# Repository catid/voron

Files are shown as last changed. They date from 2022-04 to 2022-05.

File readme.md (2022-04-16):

## Voron Files

These are some files related to Voron 2.4 printers that I've built.  Some frequently asked questions on Voron discord are answered in `faq.md`, some mods I've designed are provided and documented, and outdated copies of my personal printer configuration are provided without explanation.

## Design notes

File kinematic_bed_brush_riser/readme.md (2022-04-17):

## Voron V2 Kinematic Bed Brush Riser

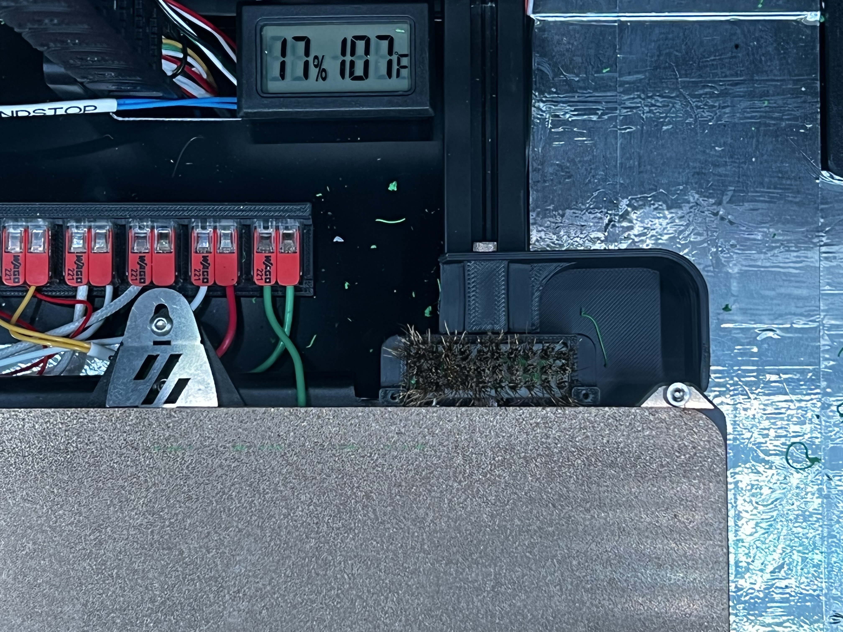
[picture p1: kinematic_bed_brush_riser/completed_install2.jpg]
Completed Install


Designed to be used with the Whoppingpochard kinematic bed mod:
https://github.com/tanaes/whopping_Voron_mods/tree/main/kinematic_bed

This may be useful for other extra-tall beds.

## Prints:

One of either of these based on your height preference:

+ `BrushRiser16mmBolts.stl` : For 2 m3x16 mm bolts.
+ `BrushRiser20mmBolts.stl` : For 2 m3x20 mm bolts.

## Assembly:

Just install it under the Purge Bucket Brush.

I had to cut off the left Purge Bucket to fit on my printer, but the right one still works fine.

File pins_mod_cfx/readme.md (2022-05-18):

## Carbon Fiber X Axis for Pins Mod

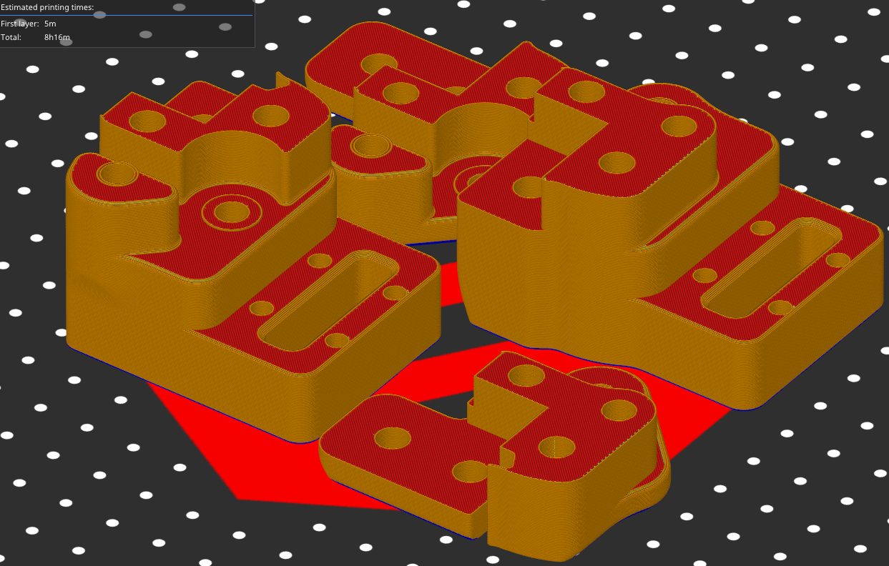
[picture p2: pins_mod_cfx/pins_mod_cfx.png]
Print


Designed to be used with the hartk pins mod:
https://github.com/hartk1213/MISC/tree/main/Voron%20Mods/Voron%202/2.4/Voron2.4_Pins_Mod/

## Prints:

+ `MGN12_xy_joint_left_lower_pinned_24r2_cfx.stl`
+ `MGN12_xy_joint_left_upper_pinned_24r2_cfx.stl`
+ `MGN12_xy_joint_right_lower_pinned_24r2_cfx.stl`
+ `MGN12_xy_joint_right_upper_pinned_24r2_cfx.stl`

## Assembly:

Just print and use in place of the original parts.

To screw in the m3 bolts for the rail, I used some pliars to hold the m3 nuts and screwed in with my other hand.

To keep the m5 nuts in place, I used some hot-glue and did one side at a time.

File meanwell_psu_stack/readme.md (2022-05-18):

## MEAN WELL 48V PSU Stack

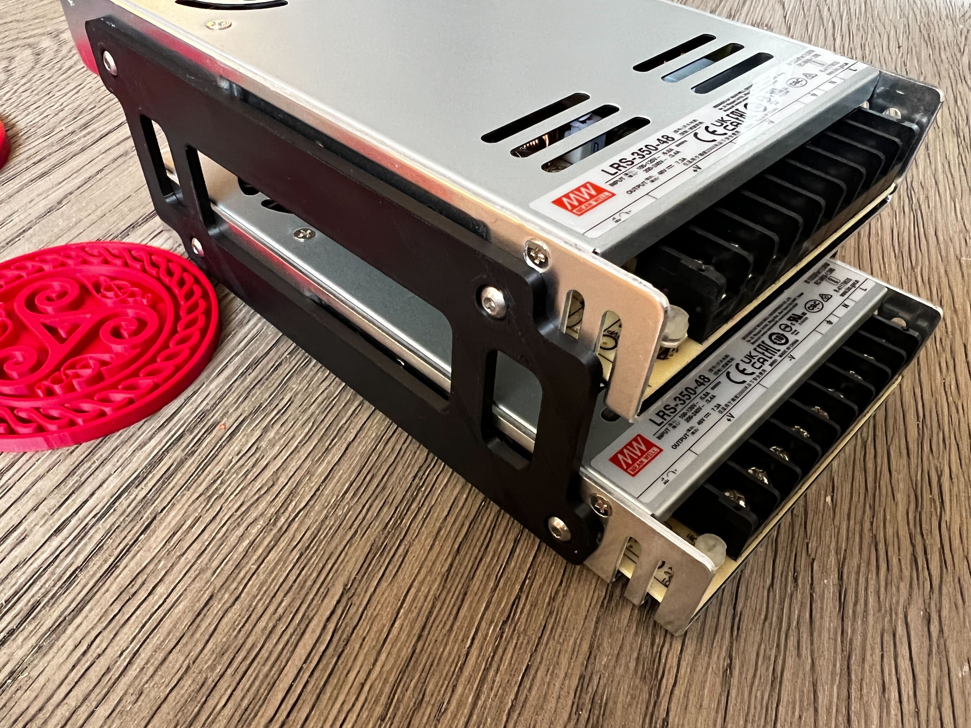
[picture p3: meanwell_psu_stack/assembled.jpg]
Assembled Stack


Because the stack is too tall for the bottom panel, I'm planning to leave off the bottom panel.

This is intended to be used for stacking a second 48V PSU on top of the first PSU in a Voron 3D printer.
My 250mm Voron is not large enough to mount a second 48V PSU in the electronics bay, and I was not able to find PSUs that were smaller and also provided enough power.

There is a 20mm offset between the two PSUs for airflow.  Both PSUs should have active cooling.  The MEAN WELL 200W PSUs do not have active cooling but the 350W versions do, and they ship fast and are fairly cheap and have good build quality.

Added an extra 20mm to the Voron feet so that the second PSU does not hit the ground, and so that it can breathe:

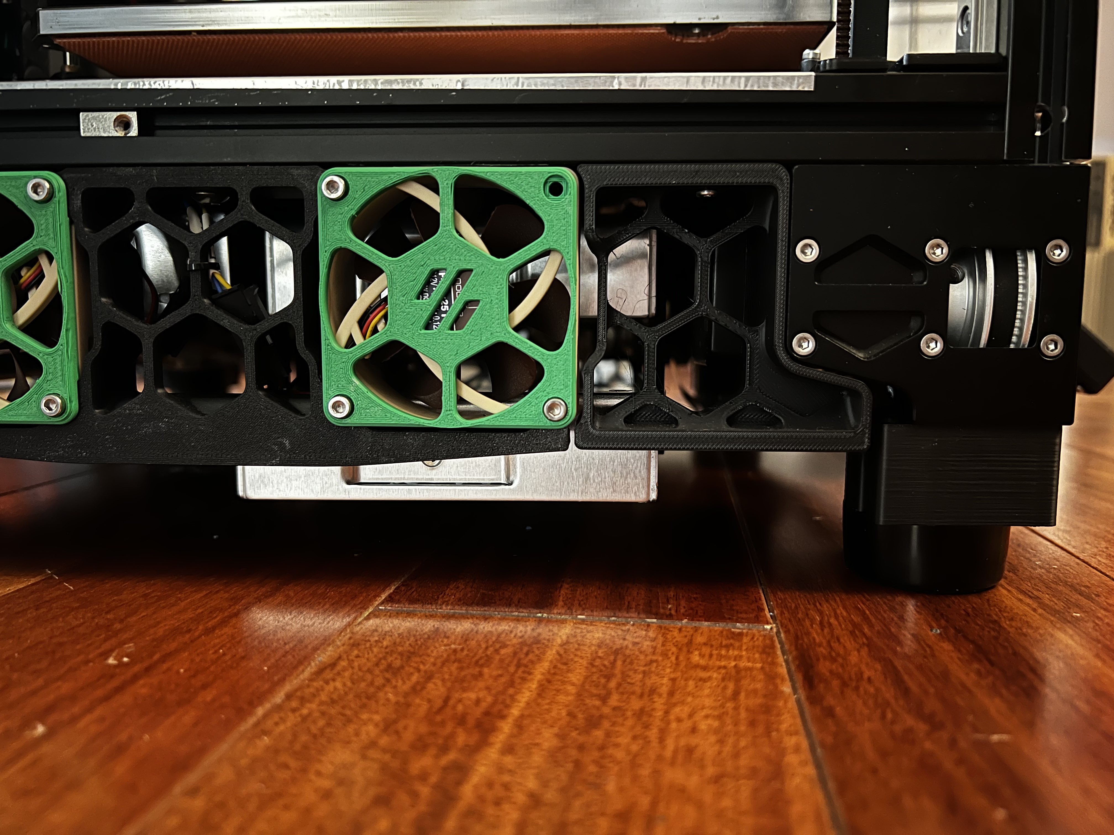
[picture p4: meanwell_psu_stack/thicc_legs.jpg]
Thicc Legs


## Materials:

Electronics:

+ 1x Actively Cooled MEAN WELL 24V PSU.  350W version works.
+ 1x Actively Cooled MEAN WELL 48V PSU.  350W version works.

Fasteners:

+ 8x m4x6 bolts

## Prints:

+ 1x `MeanwellStackLeft.stl`
+ 1x `MeanwellStackRight.stl`
+ 2x `FootSpacerAx2.stl`
+ 2x `FootSpacerBx2.stl`

They should fit on a 250mm build plate.

## Assembly:

Install using the m4x6 bolts so that the terminals are exposed as in the picture above.  Then install as normal using the typical Voron mounting option.

The bottom panel should be left off with this mod, since the stack is too tall.

The normal Voron feet spacers should be replaced by the thicc ones, which add an extra 20mm of height under the printer so that the 48V PSU can breathe and so that it doesn't hit the floor.

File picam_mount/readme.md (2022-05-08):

## Voron V2 Pi Camera Mount

Example video produced by this design: https://www.youtube.com/watch?v=63CIvoFfxug

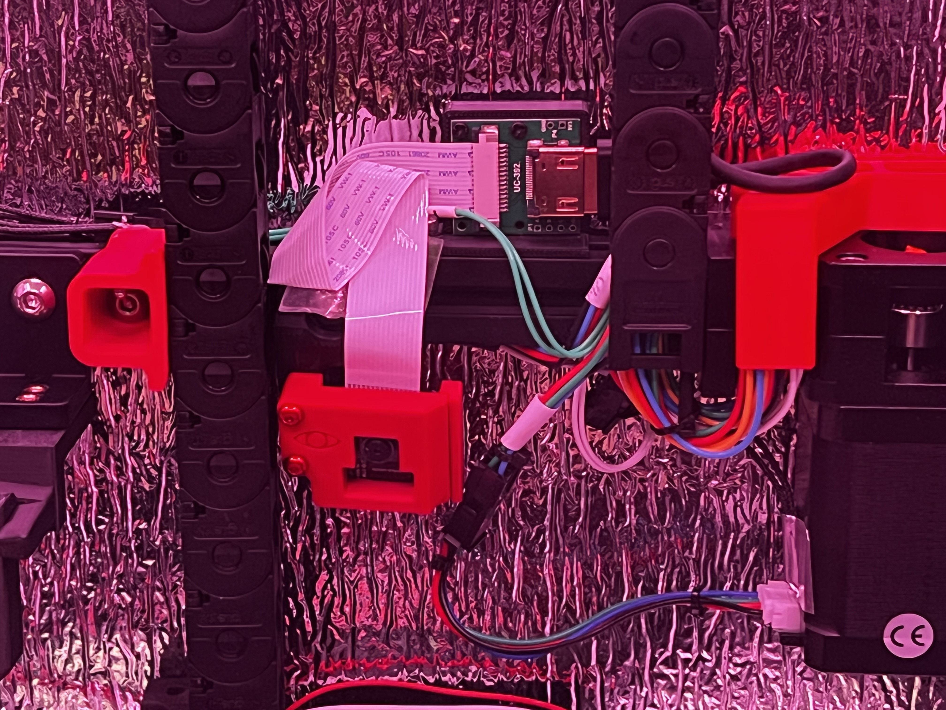
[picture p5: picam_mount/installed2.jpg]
Completed Install


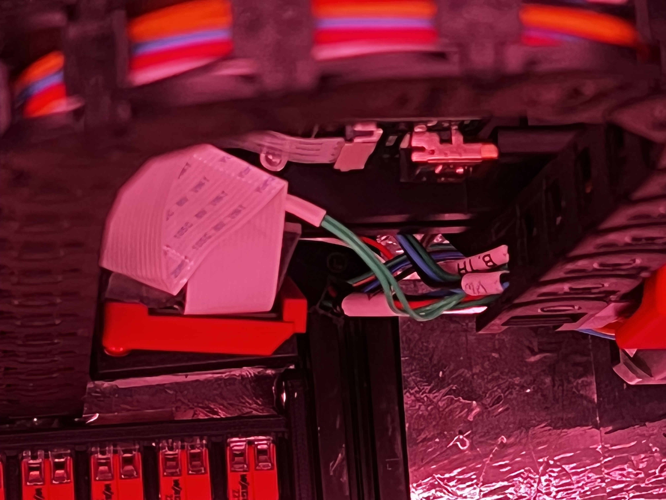
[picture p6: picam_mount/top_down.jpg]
Top Down


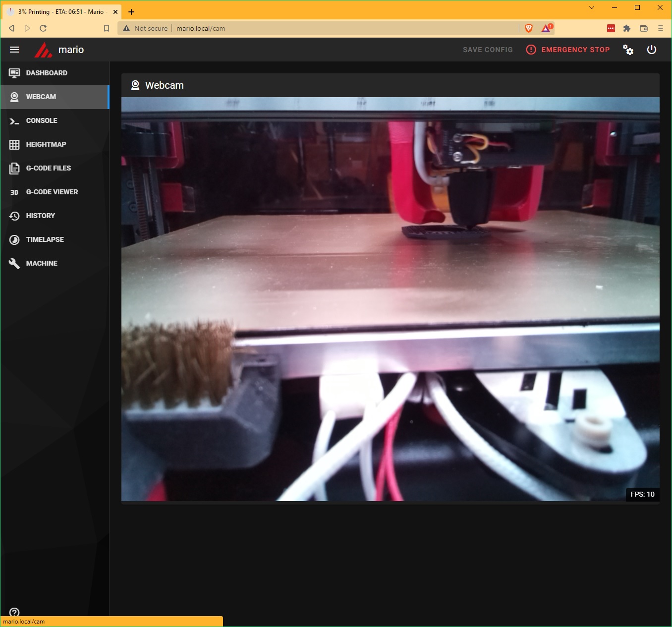
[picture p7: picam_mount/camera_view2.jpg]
Camera View


## Materials:

Electronics:

+ Official Raspberry Pi Camera Module V2 8-megapixel sensor 3280 × 2464 1080p V2.1 for Raspberry Pi 3 2 1 model B B+
+ Arducam CSI to HDMI Cable Extension Module with 15pin 60mm FPC Cable for Raspberry Pi Camera Specific (Pack of 2, 1 Set)
+ 3 foot (1 meter) HDMI cable.
+ You might need a slightly longer PiCam MIPI cable to reach from the adapter to the camera.

Fasteners:

+ Small screws that come with the HDMI adapters and PiCam - Do not throw these away!  If you lost some you can use 2-3 screws instead of 4 and share between the mounts.
+ 2x m3 Heatset insert
+ 2x m3x12 bolts (for camera)
+ 2x m3x8 bolts (for HDMI adapters)
+ 2x m3 2020 T-nut insert (for HDMI adapters)
+ 1x m5 2020 T-nut insert (for camera)
+ 1x m5x10 bolt (for camera mount)
+ Some double-sided tape to secure the MIPI cable

## Prints:

One of each of the STLs included:

+ `2020Mount.stl` : Attaches to gantry on the side under the Z cable chain.
+ `PCBHolder.stl` : Bolts to the 2020Mount and carries the Pi camera.  Small screws that come with the Pi can secure it down.
+ `CaseTop.stl` : Bolts to the PCBHolder and provides some protection for the camera.
+ `PiCamHdmiAdaptMountBay.stl` : Attaches to the side of any open 2020 extrusion near the Pi.  Terminates HDMI cable, provides PiCam CSI ribbon cable.
+ `PiCamHdmiAdaptMountGantry.stl` : Attaches to gantry on the top behind the Z cable chain, flush against the AB motor housing.  Terminates PiCam CSI ribbon cable, provides HDMI cable.

## Assembly:

Install heatset inserts into the two holes in the 2020Mount.

Install the two HDMI adapters into their mounts with their tiny bolts.

Bolt one to the top of gantry (with T-nut), and route the HDMI cable through the Z cable chain.  Bolt the other one into the electronics bay (with T-nut) close enough to the Raspberry Pi so that a CSI ribbon cable will reach to the (center) CSI port on the Pi.
Note that the one for the gantry will send the HDMI cable to the right, while the one for the electronics bay sends HDMI the wrong way for use on the gantry.

Bolt 2020Mount onto side of gantry (with T-nut) between Z cable chain.

Attach Pi camera to the HDMI adapter via ribbon cable.

Bolt PCBHolder to 2020Mount first, and then install the Pi camera with tiny bolts.
Bolt CaseTop to PCBHolder.

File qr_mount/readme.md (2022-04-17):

## Voron V2 Bondtech QR Extruder Mount

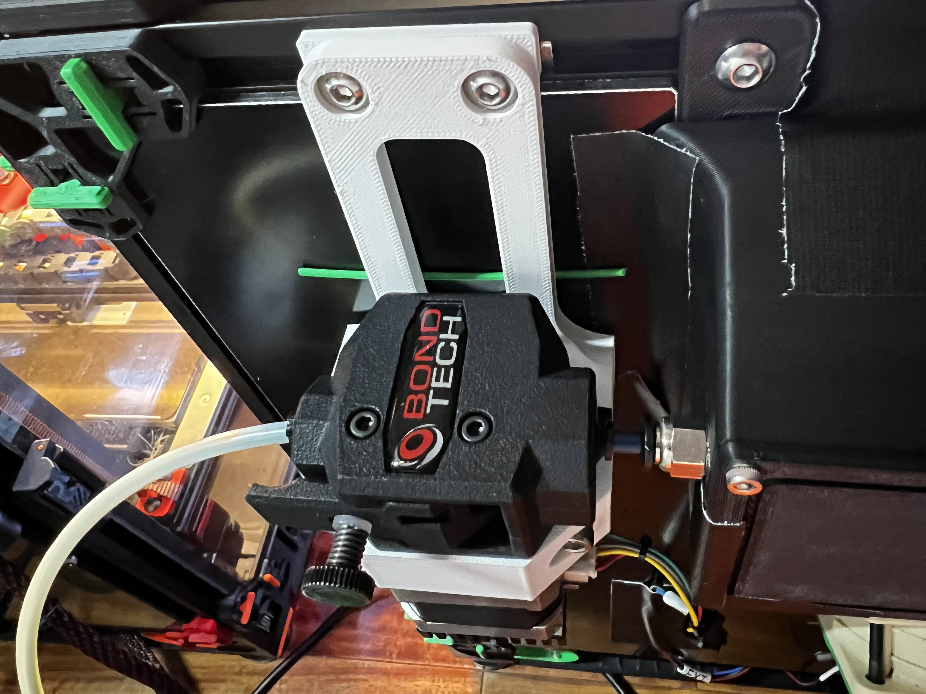
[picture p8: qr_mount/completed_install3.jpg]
Completed Install


## Materials:

Electronics:

+ Bondtech QR Extruder

Fasteners:

+ 2x m3 T-nuts
+ 2x m3x8 bolts
+ 2x m5x20 bolts
+ 2x m5 nuts

## Prints:

One of each of the STLs included:

+ `QRMountSpacer.stl` : Offsets the QRMountBody from the frame by the width of the back panel (3mm).
+ `QRMountBody.stl` : Carries the extruder.  Has nut traps underneath.  Should be held away from the back panel using a piece of filament to avoid vibration.
+ `QRMountTop.stl` : Locks in the extruder.

Designed to be used with this mod:
https://github.com/VoronDesign/VoronUsers/tree/master/printer_mods/120decibell/exhaust_housing_side_entry

## Assembly:

Install the Bondtech QR Extruder into the QRMountBody using the QRMountTop.  Install nuts in the nut traps and screw the two m5 bolts into place.

Using the QRMountSpacer, bolt the QRMount assembly to the frame with T-nuts so that it is a short distance from the `exhaust_housing_side_entry` entry port.
The Bowden tube should line up precisely with the entry port on the other mod, so that the tube length is as short as possible.

To keep the extruder from vibrating against the back, place a bit of filament about mid-way up the mount along the back panel.

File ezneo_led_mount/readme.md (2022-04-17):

## Voron V2 ezNeo LED Brackets

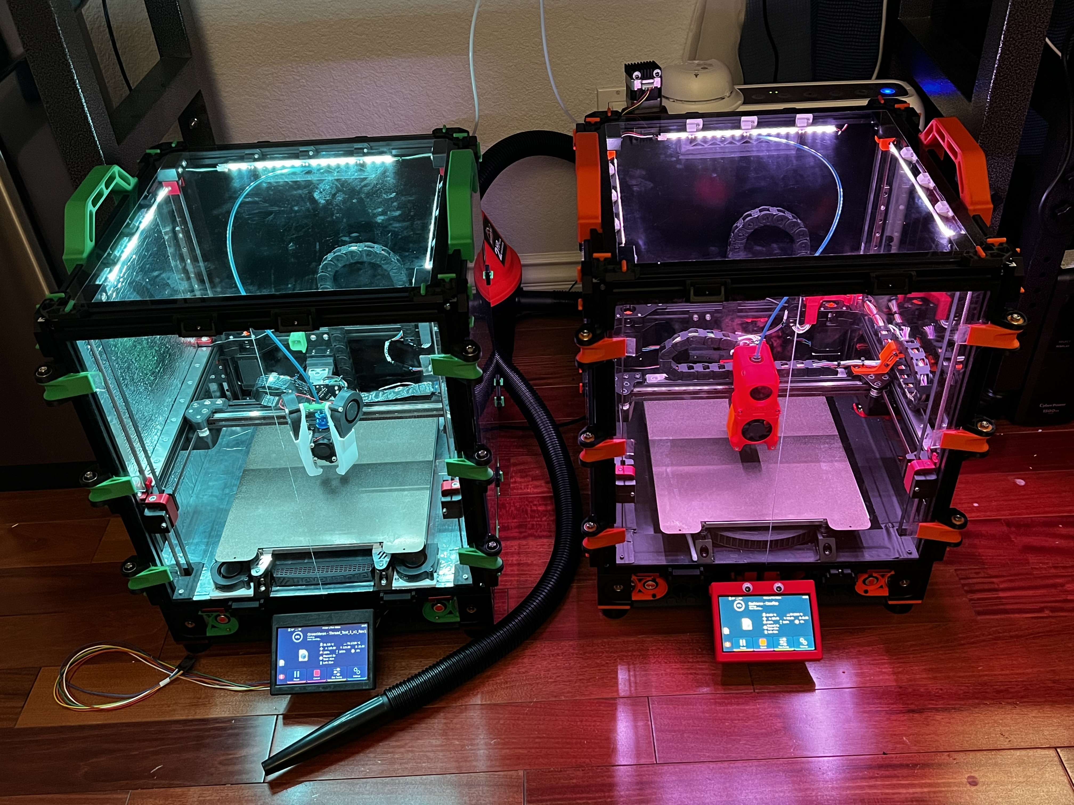
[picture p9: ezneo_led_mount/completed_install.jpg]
Completed Install


Designed to be used with the ezNeo LED boards:
https://www.th3dstudio.com/2021/07/16/add-rgb-to-your-3d-printer-with-our-ezneo-kits/

## Prints:

You will need 3x `ezNeoLEDbracket.stl` for each board.

## Assembly:

Insert heatset inserts into the larger hole on each bracket.

Bolt the brackets to the board, and then bolt the brackets+board to the 2020 frame.

## Chaining PCBs

Extra step requires soldering and crimping connectors:
To chain the ezNeo boards together, use multimeter to find the SignalOut, Vin, and GND pins at the end of the board, and solder a pigtail that can be connected to the next board.
This way you can use just 3 cables to connect the LEDs to your mcu, which usually only has one LED port.

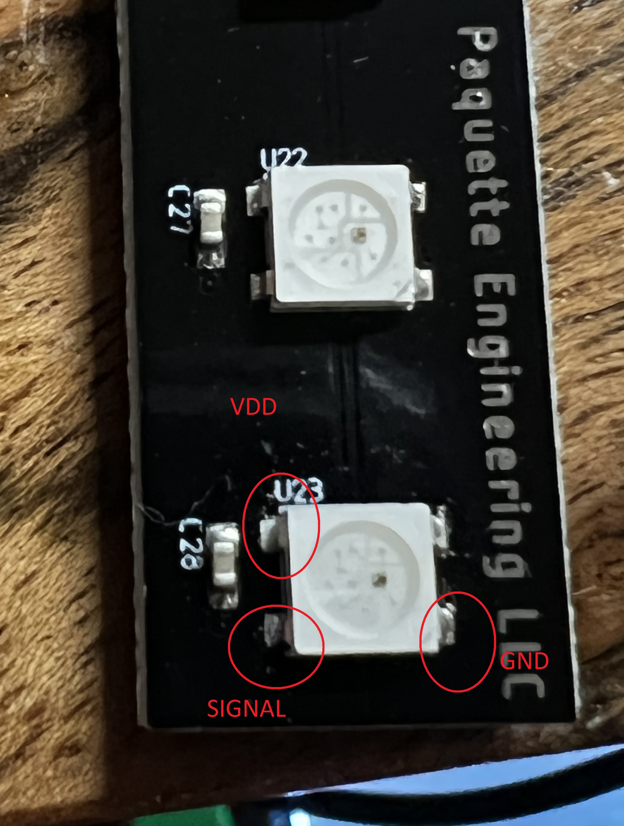
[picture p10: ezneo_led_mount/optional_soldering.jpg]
Optional Soldering


## Adding Diffusers

Extra step requires a drill (and ideally a center punch):
You can buy some diffusers that are the width of these boards and drill holes in them to mount with the m3x8 bolts.

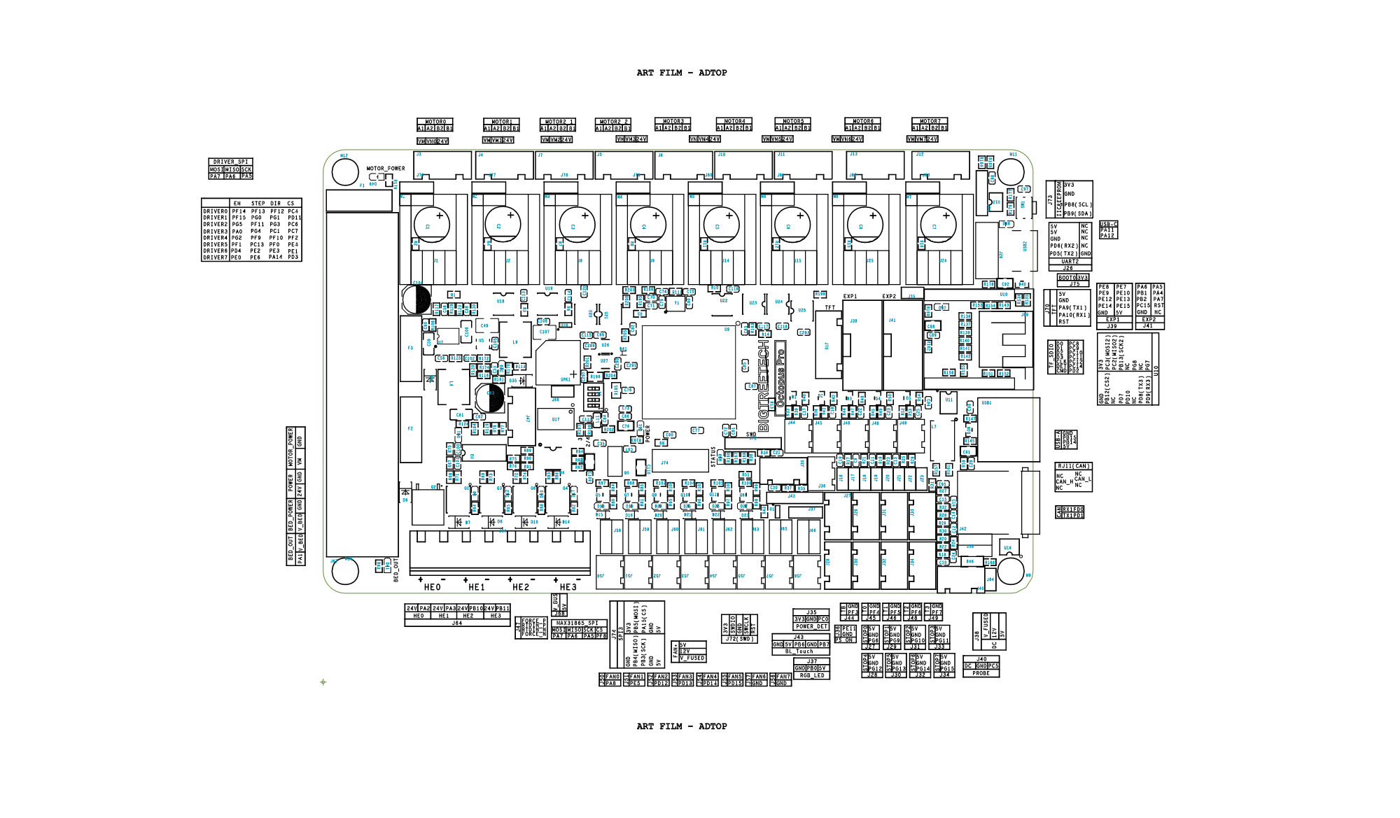
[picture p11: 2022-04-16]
printers/redvoron/octopus_pro_pinout.png

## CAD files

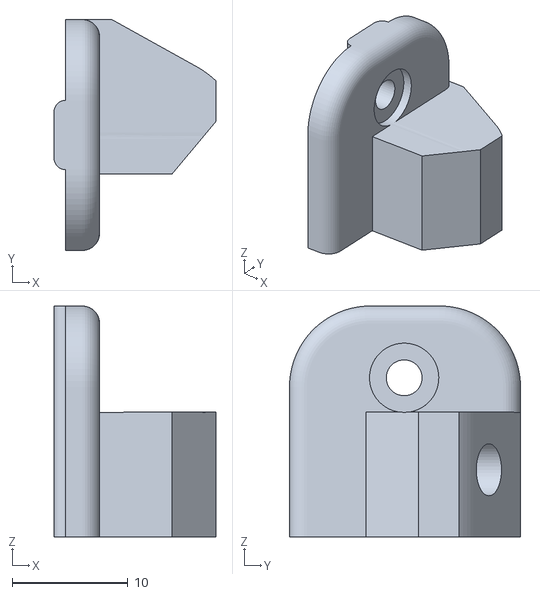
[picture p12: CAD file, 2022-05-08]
ezneo_led_mount/ezNeoLEDbracket.stl
14.0 x 20.0 x 20.0

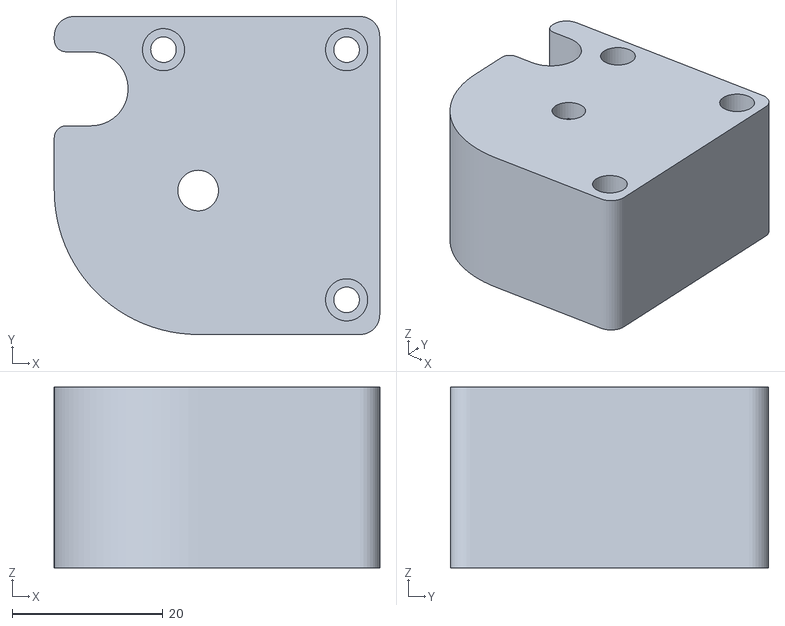
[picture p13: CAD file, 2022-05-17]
meanwell_psu_stack/FootSpacerAx2.stl
43.2 x 42.2 x 24.0

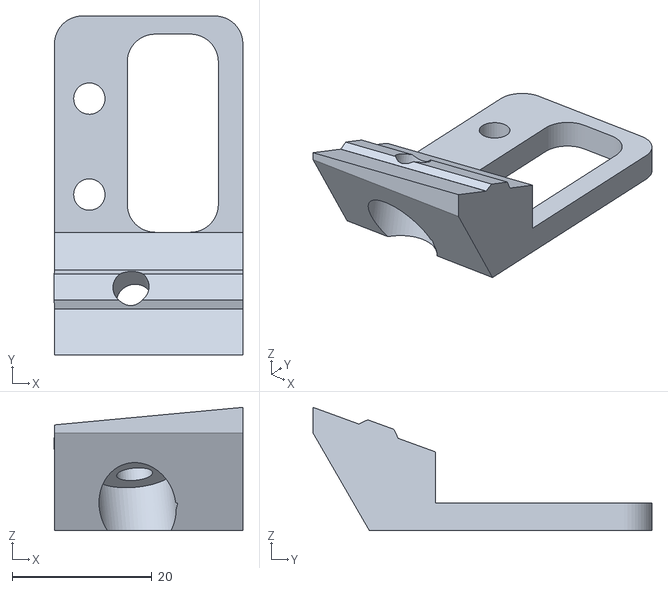
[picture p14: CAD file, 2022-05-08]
picam_mount/2020Mount.stl
27.1 x 48.6 x 17.7

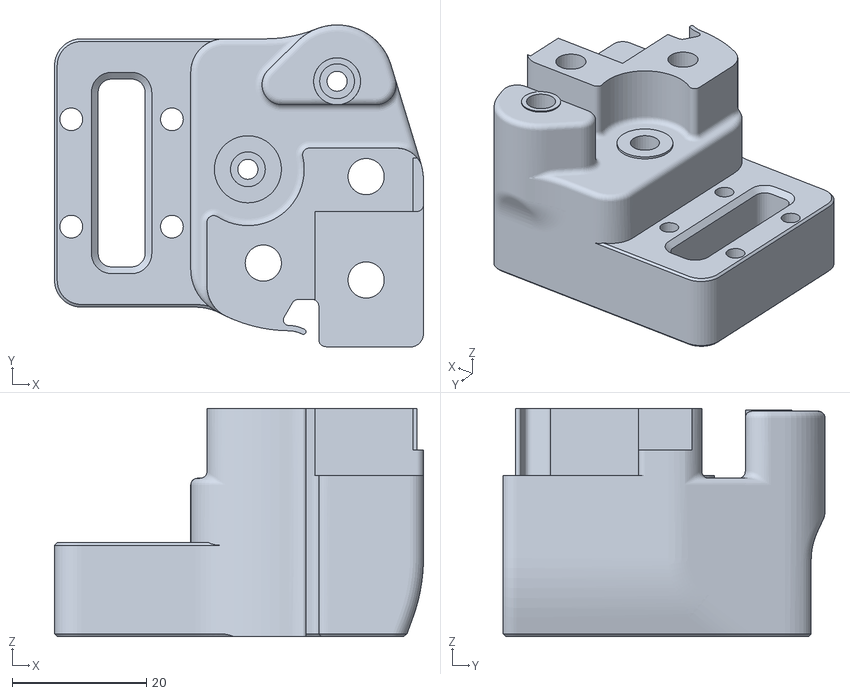
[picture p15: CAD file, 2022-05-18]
pins_mod_cfx/MGN12_xy_joint_right_lower_pinned_24r2_cfx.stl
55.0 x 48.0 x 34.0

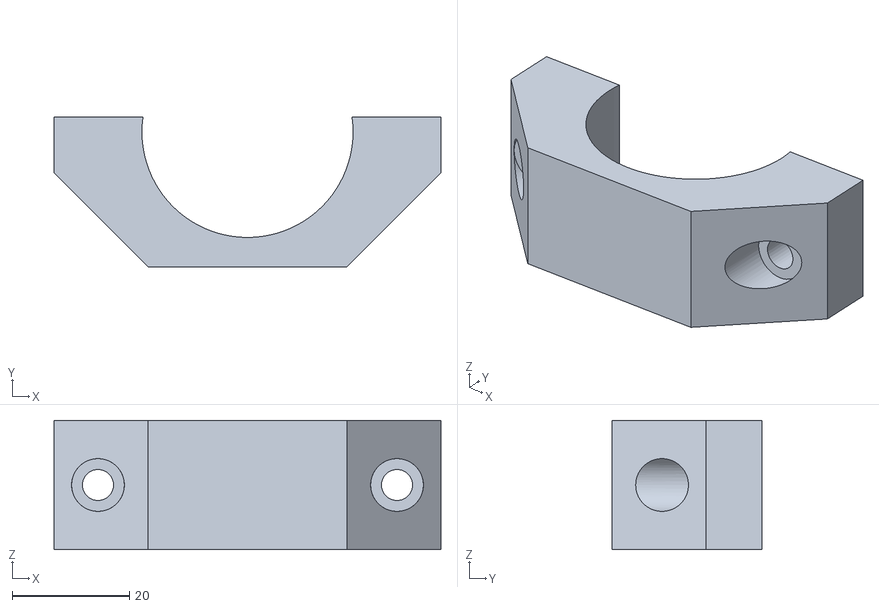
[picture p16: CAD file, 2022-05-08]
qr_mount/QRMountTop.stl
66.0 x 25.5 x 22.0

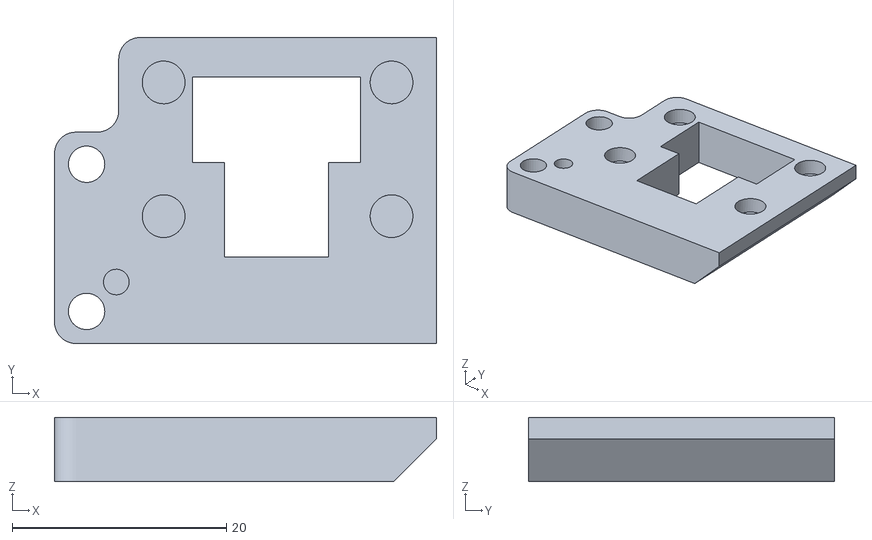
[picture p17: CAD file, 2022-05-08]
picam_mount/CaseTop.stl
35.7 x 28.6 x 6.00

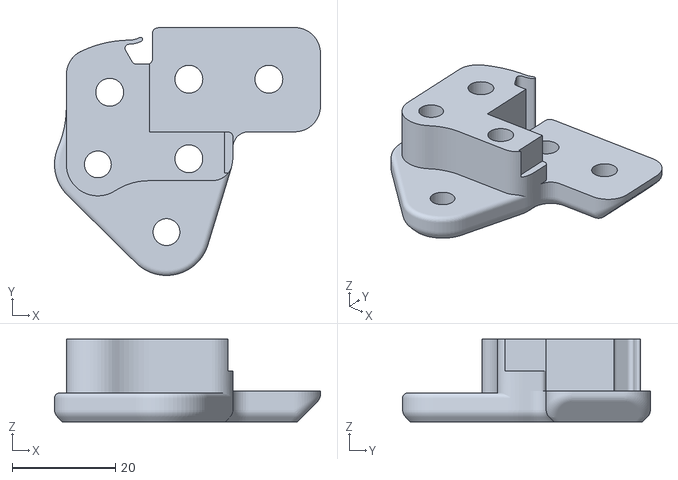
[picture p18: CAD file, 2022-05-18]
pins_mod_cfx/MGN12_xy_joint_right_upper_pinned_24r2_cfx.stl
51.5 x 48.0 x 16.0

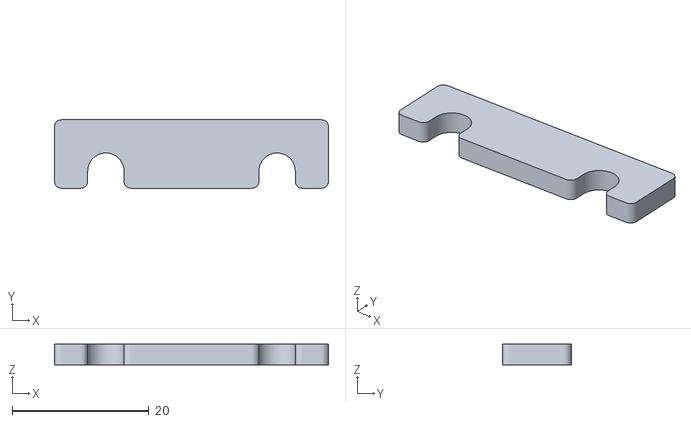
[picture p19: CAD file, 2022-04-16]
qr_mount/QRMountSpacer.stl
40.0 x 10.0 x 3.00

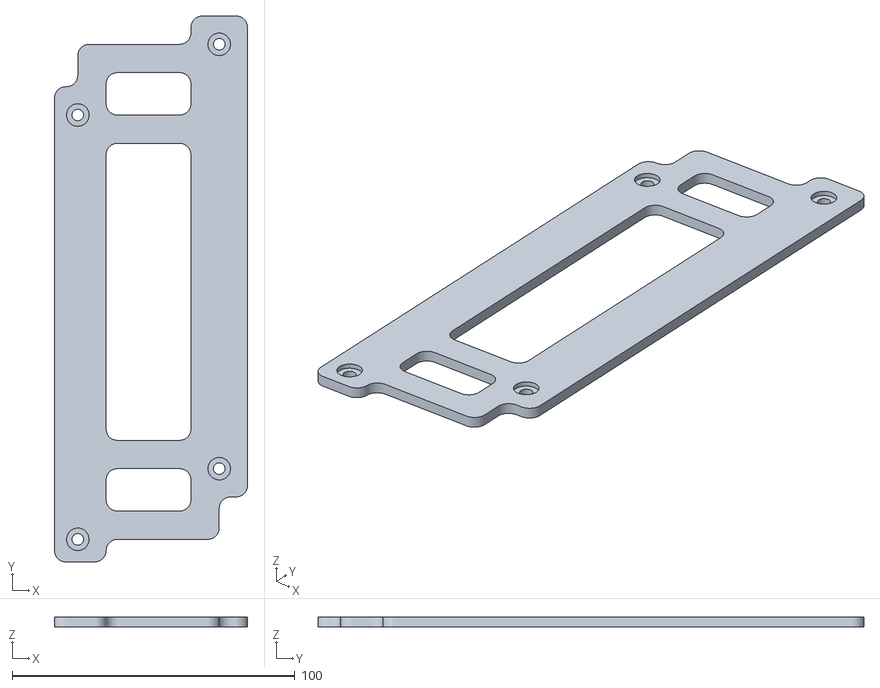
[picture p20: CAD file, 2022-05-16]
meanwell_psu_stack/MeanwellStackRight.stl
68.2 x 193.0 x 3.50

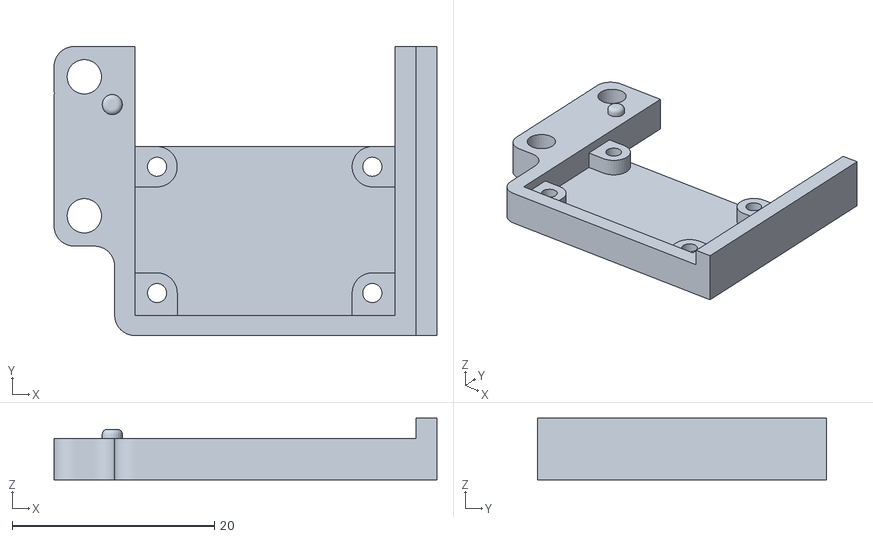
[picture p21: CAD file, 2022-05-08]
picam_mount/PCBHolder.stl
37.9 x 28.6 x 6.10

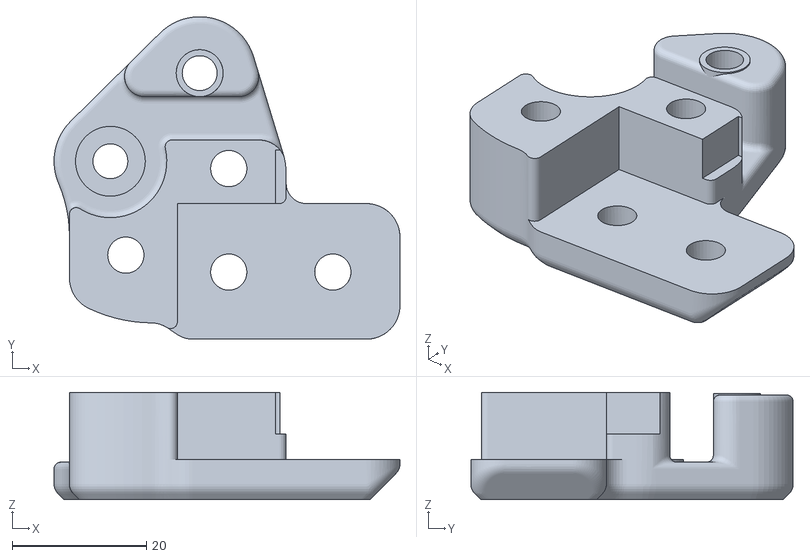
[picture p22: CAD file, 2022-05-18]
pins_mod_cfx/MGN12_xy_joint_left_upper_pinned_24r2_cfx.stl
51.5 x 48.0 x 16.0

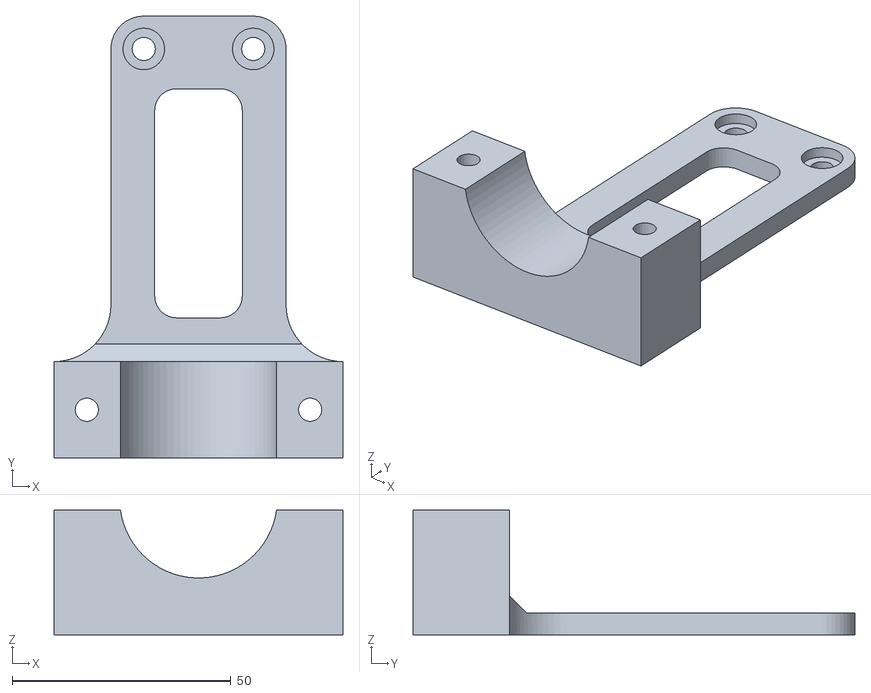
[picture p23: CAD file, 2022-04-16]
qr_mount/QRMountBody.stl
66.0 x 100.9 x 28.5

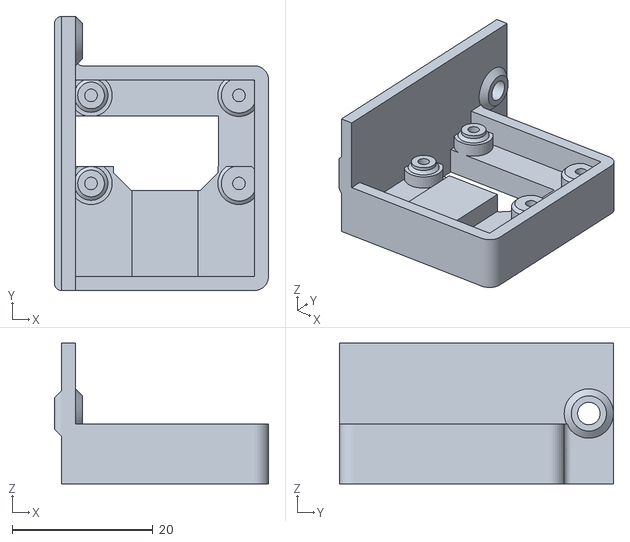
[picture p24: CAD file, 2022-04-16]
picam_mount/PiCamHdmiAdaptMountGantry.stl
30.4 x 38.9 x 20.0

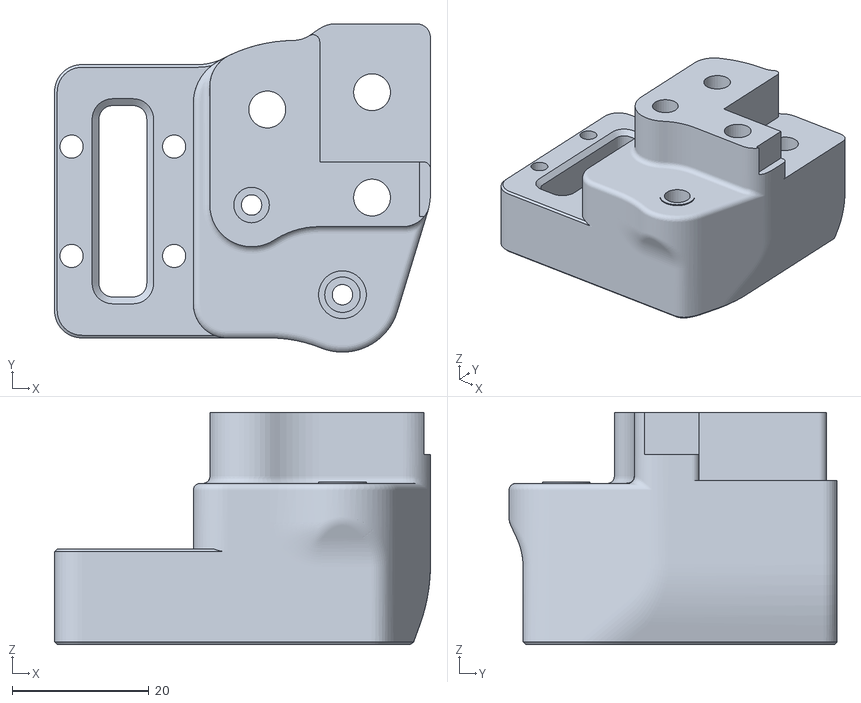
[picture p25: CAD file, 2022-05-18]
pins_mod_cfx/MGN12_xy_joint_left_lower_pinned_24r2_cfx.stl
55.0 x 48.0 x 34.0

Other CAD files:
meanwell_psu_stack/FootSpacerBx2.stl
meanwell_psu_stack/MeanwellStackLeft.stl
picam_mount/PiCamHdmiAdaptMountBay.stl
kinematic_bed_brush_riser/BrushRiser16mmBolts.stl
kinematic_bed_brush_riser/BrushRiser20mmBolts.stl

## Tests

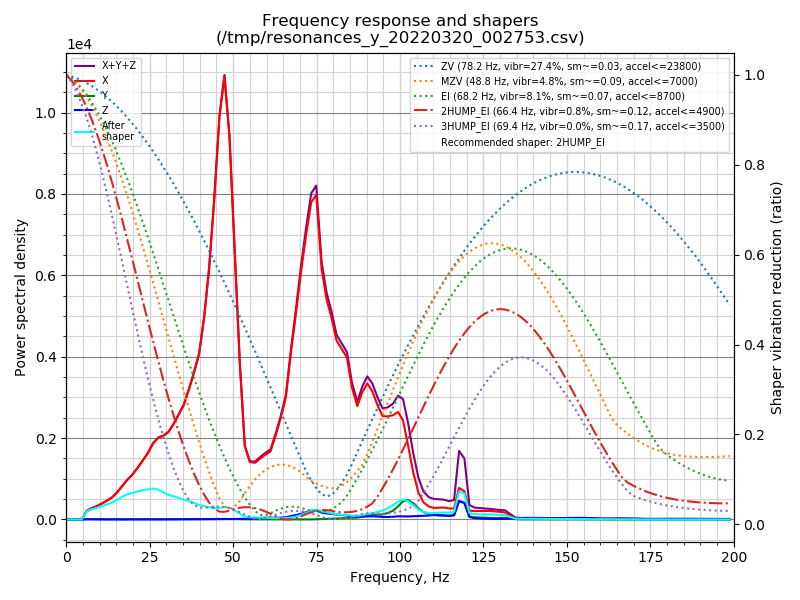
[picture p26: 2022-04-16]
printers/redvoron/shaper_calibrate_y.png

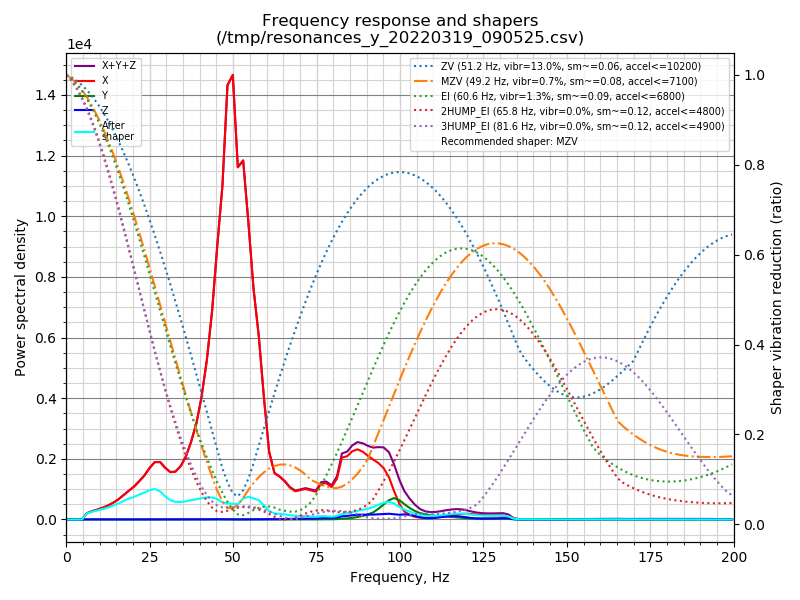
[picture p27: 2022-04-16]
printers/redvoron/130hz_shaper_calibrate_y.png

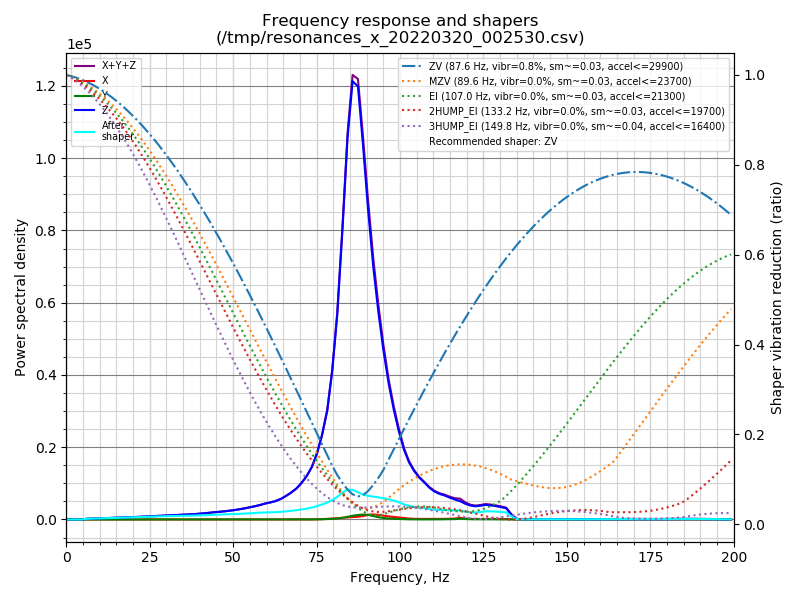
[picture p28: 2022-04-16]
printers/redvoron/shaper_calibrate_x.png

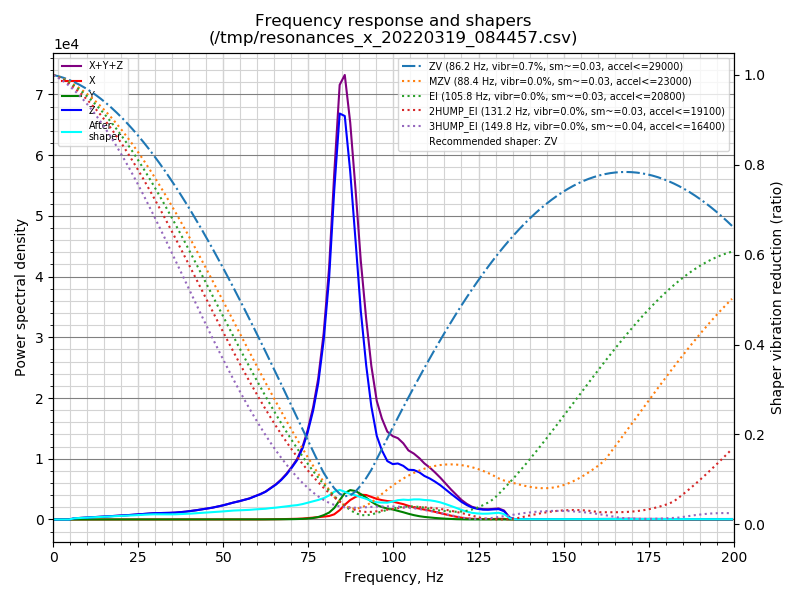
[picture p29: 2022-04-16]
printers/redvoron/110hz_shaper_calibrate_x.png

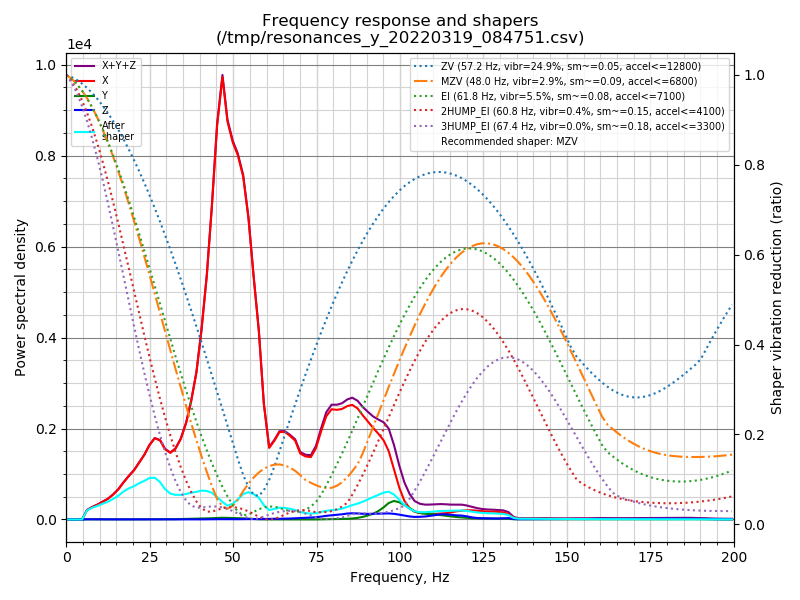
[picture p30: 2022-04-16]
printers/redvoron/110hz_shaper_calibrate_y.png

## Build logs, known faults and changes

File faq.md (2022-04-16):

## Motor is losing steps:

So there are a few common causes for motors to lose steps.  First off, disable motor power and move the toolhead along both diagonals by hand.  Not in X/Y direction: 45 degrees so that only one motor spins at a time.  You should feel the same resistance both ways.  If one side is even slightly harder to move, then check if that belt path is wrapped around a post in the back.  It may also not run through the center of the pulleys, idlers, and bearings in the gantry and be rubbing on the sides.  You might find belt dust accumulating somewhere, or see wear on the sides of the belts.
Another thing that can happen is your grub screws have come loose on one of the AB motors.  You can make this easier to check by buying some CrossCheck and pasting a little line across the pulley/rotor that will break if the grub screws are loose.
It could also be that the crimps on the wires going to the AB motors are not tight, so during motion the motors are losing power.  This one is harder to diagnose but might happen more or less if you wiggle the cables.
Finally you might have an issue in the printer.cfg motor settings.  For example the run_current might need to be set higher to achieve the speeds you are requesting without missing steps.

## Motor is not spinning:

If a motor is not spinning, is stuttering, or causing Klipper errors then it is likely not wired properly.  To fix it you can use a multimeter to figure out how it should be wired, since the colors or positions of the wires from the motor do not mean anything.
First make sure that your printer is powered off!  An easy test is to take a multimeter and press the probe to the first two pins on the JST-XH connector, after removing it from the mcu.
You should see close to 0 ohms resistance that increases to ~11 ohms or so after a while.  Then test the next two pins (BB) and check again.  Final check the center pins to make sure you get infinite resistance (open circuit).
If you find that it's wired ABBA, then the easiest fix is to use one end of some tweasers to press under the pin housing and release the JST crimp clasp to allow the pins to slide out, use your fingernail to prop the crimp clasp back up so it will hold tight in the new hole.  With this method, swap two pins on the JST connector so that there is no need to re-crimp.

## Motors are noisy at higher speeds:

Make sure Stealthchop is turned off.

## How to configure motor current:

Setting run_current higher helps reduce the noise from the printer, and it will unlock faster speeds.  Do you know what the rated current is, or type of A and B motors you're using?  Typically you want 85% of the RMS current.  For LDO 0.9 degree steppers that are rated for 2A peak - divide by sqrt(2) - that means 1.41A RMS and 1.2A at 85%.  For 1A motors used for extruder, people tend to use 0.5 in Klipper for run_current.

## How to configure motor microsteps:

Setting microsteps higher reduces noise from the printer and may help unlock faster speeds.  You can increase motor microsteps until the mcu starts printing a mcu timer error in the Klipper logs.  LDO 0.9 degree steppers seem to max out around 128 microsteps, while 1.8 degree steppers max out at 256.

## No MGN12 rail:

If you do not have a MGN12H rail but instead two MGN9H rails for the X axis, you'll want the 2.4 parts for the X axis XY joints rather than the 2.4r2 ones.  You can find them under STLs/Superceded_Parts/MGN9_X.
For the rest of the printer you can use the improved 2.4r2 parts, and you can reference the 2.4r2 assembly manual and other docs during your build.

## Belts rubbing on the side panels:

The side panels need to have 3mm foam tape (weather stripping) applied around the perimeter so that the gantry belts do not rub on them.

## Improved side/top panel clips:

There are options for bolted, magnetic, and locking corners.  The bolted ones are a pain to take on and off.  The magnetic ones tend to fall off very easily in practice, so are not recommended.  The locking corner clips are excellent and require no fasteners or magnets to build:
https://github.com/Annex-Engineering/Other_Printer_Mods/tree/master/All_Printers/Annex_Panel_2020_Clips_and_Hinges/panel_clips_and_corners/

The corners are under `corner/STL`, and should be sized to the panel+foam tape width.  For example for 3mm top panel with 1mm foam tape, you'd use the 4mm corner piece x4.  And for the sides you might have 3mm panels with 3mm foam tape, so 6mm corner pieces.
Similarly you'd need to print the keys from `key/STL` sized appropriately for your panels.

To avoid gaps in the side panels, you can also print a few `single/STL` that twist lock onto the middle of the side panels.

It's also a good idea to buy some Plexus plastic cleaner, because it makes the panel surface much more slick, more clear, and better at resisting dust.

## Improved door panels:

There are a few options for the door panel hinges.  I've found that the hinges with the smoothest motion are found here:
https://github.com/Annex-Engineering/Other_Printer_Mods/tree/master/All_Printers/Annex_Panel_2020_Clips_and_Hinges/hinge/screw_mount/R4_625/STL
These require M5x40mm bolts, 12 625 bearings (not the flanged ones), and 24 m5 1mm spacers/washers (to make them even smoother).  3 on each side will provide plenty of support for the tape supporting the panels while they are open.

To provide some support for the doors and allow them to be easily latched down, I'd recommend printing a snap-latch-2020 for the top and bottom of each door panel: https://github.com/VoronDesign/VoronUsers/tree/master/printer_mods/richardjm/snap-latch-2020

## Adding handles:

The best handles I've found are the Sturdy Handles, since these stay clear of the panels and do not need to be removed if the panels are removed:
https://github.com/VoronDesign/VoronUsers/tree/master/printer_mods/jeoje/Sturdy_Handles

## Kits:

Buying a kit to build a Voron may take longer than self-sourcing and can be more expensive.  You will wait longer for the kit to arrive, and some of the parts will not be the best ones for your build, or may be unreliable where you need quality: e.g. SSR or inductive probe.  So you may end up buying some parts twice if you order a kit.  It's best to buy subkits from vendors you can find on the Voron Discord under the VENDORS section - Just google the store name and search to see what they offer, and you'll find subkits for parts that you need that will ship faster than from China and often with higher quality.
Ordering the cable chains directly from IGUS on digikey.com is a good idea, as they ship quickly and I've had trouble with intermediate vendors selling kits at a markup not including the right parts.

## Wires in cable chains:

The wires going through the chains should be PTFE and not be twisted or have anything else like zip-ties on them.  The reason to keep it simple is to avoid kinks forming that will cause the cables to break after a while.
Silicone wire is not as good as PTFE for cable chains mainly because PTFE cables are self-lubricating and slide past eachother in the cable chains, and they're also smaller diameter so it's easier to run the cables through.

## Warning about Loctite:

Loctite eats away ABS plastic and will cause it to become brittle.  Only use Loctite on metal parts (inside T-nuts or bolts, on grub screws) and in small amounts.  The damage it causes to plastic parts is not obvious visually, and it's worth replacing parts that were accidentally exposed to Locktite.

## Tuning overhang cooling to fix sagging:

Probably you need more fan speed when printing overhangs.  The settings in SuperSlicer are `Filament Settings > Cooling > Bridges fan speed = 82%` to set the speed of the fan and `Print Settings > Perimeters & Shell > Overhangs > threshold for [X] Bridge speed and fan: 40%` to set the angle at which the bridge fan speed is used.
To tune it I would recommend using the SuperSlicer `Calibration > Filament Temperature Calibration` test print and pay attention to the overhang part to determine the angle at which you need more fan.  And then do a bunch of test prints at different fan speeds to find the settings that work for your filament and printer.  You may find that a higher or lower nozzle temperature may perform better overall.

## How to tune SuperSlicer Extrusion Multiplier and Klipper pressure_advance:

The simple way to calibrate EM/PA is to run a grid search with lots of generated cubes using your normal printing speed and settings.  In SuperSlicer, Generate > FreeCAD and enter cube(30, 30, 0.45).  Copy the cube 5 times and edit each one: Right-click a cube, Add Settings > Filament > Extrusion multiplier  and assign each one a different EM multiplier from 0.98, 0.99, 1.0, 1.01, 1.02.

While printing, pay attention to any of the perimeters to tune PA.  If the perimeter lines do not touch, then your PA is too low and you can slowly tune it higher.  If the corner lines do not touch, then your PA is too high and you can slowly tune it lower.

After the print finishes, feel the tops of the cubes.  If they feel rough parallel to the lines, then EM is too high.  If they feel rough perpendicular to the lines, then EM is too low.  They should feel smooth in both directions.  Your favorite cube indicates how to adjust the EM, -2% to +2% around the current EM in your print settings.  Just multiply the EM multiplier by what you have and update it.  Then do it again until you're happy with the smoothness. 

## Genuine Gates Pulleys/Idlers:

According to Ellis' tuning guide using genuine parts for the XY gantry is a good idea for print quality: https://github.com/AndrewEllis93/Print-Tuning-Guide/blob/main/articles/troubleshooting/vfas.md

https://www.filastruder.com/products/gates-2gt-pulley?variant=15443750518855
https://www.filastruder.com/products/gates-2gt-idler?variant=15443755728967

## The mainsailos.local domain does not resolve in the browser:

You may need to install Bonjour services on your Windows computer: https://support.apple.com/kb/DL999?locale=en_US
You can also edit the hostname of your Pi in sudo raspi-config then 1 System Options > S4 Hostname so you can give it a more fun name

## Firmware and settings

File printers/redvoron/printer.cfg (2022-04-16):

[include mainsail.cfg]
[include timelapse.cfg]

# This file contains common pin mappings for the BigTreeTech Octopus V1.
# To use this config, the firmware should be compiled for the STM32F446 with a "32KiB bootloader"
# Enable "extra low-level configuration options" and select the "12MHz crystal" as clock reference

# after running "make", copy the generated "klipper/out/klipper.bin" file to a
# file named "firmware.bin" on an SD card and then restart the OctoPus with that SD card.

# See docs/Config_Reference.md for a description of parameters.

## Voron Design VORON2 250/300/350mm BigTreeTech OctoPus V1 TMC2209 UART config

## *** THINGS TO CHANGE/CHECK: ***
## MCU paths                            [mcu] section
## Thermistor types                     [extruder] and [heater_bed] sections - See 'sensor types' list at end of file
## Z Endstop Switch location            [safe_z_home] section
## Homing end position                  [gcode_macro G32] section
## Z Endstop Switch  offset for Z0      [stepper_z] section
## Probe points                         [quad_gantry_level] section
## Min & Max gantry corner postions     [quad_gantry_level] section
## PID tune                             [extruder] and [heater_bed] sections
## Thermistor types                     [extruder] and [heater_bed] sections
## Probe pin                            [probe] section
## Fine tune E steps                    [extruder] section

[mcu]
serial: /dev/ttyAMA0
restart_method: command

[printer]
kinematics: corexy
max_velocity: 500
max_accel: 20000
max_accel_to_decel: 20000
max_z_velocity: 25
max_z_accel: 1000
square_corner_velocity: 7.0

[input_shaper]
shaper_freq_x: 89.6
shaper_type_x: zv
shaper_freq_y: 48.8
shaper_type_y: mzv

#####################################################################
#   X/Y Stepper Settings
#####################################################################

##  B Stepper - Left
##  Connected to MOTOR_0
[stepper_x]
enable_pin: !PF14
step_pin: PF13
dir_pin: !PF12
endstop_pin: PG6

rotation_distance: 40
full_steps_per_rotation: 400  #set to 400 for 0.9 degree stepper

microsteps: 128

position_min: 0
position_endstop: 246
position_max: 246

homing_speed: 50
homing_retract_dist: 6
homing_positive_dir: true

[tmc5160 stepper_x]
#   https://www.klipper3d.org/TMC_Drivers.html
#   https://github.com/bigtreetech/BIGTREETECH-TMC5160-V1.0
cs_pin: PC4
spi_bus: spi1
sense_resistor: 0.075

run_current: 1.2
interpolate: false
#stealthchop_threshold: 9999
stealthchop_threshold: 0

##  A Stepper - Right
##  Connected to MOTOR_1
[stepper_y]
enable_pin: !PF15
step_pin: PG0
dir_pin: !PG1
endstop_pin: PG9

rotation_distance: 40
full_steps_per_rotation: 400  #set to 400 for 0.9 degree stepper

microsteps: 128

position_min: 0
position_endstop: 256
position_max: 259 # extra 3 for Klicky mod

homing_speed: 50
homing_retract_dist: 6
homing_positive_dir: true

[tmc5160 stepper_y]
cs_pin: PD11
spi_bus: spi1
sense_resistor: 0.075

run_current: 1.2
interpolate: false
#stealthchop_threshold: 9999
stealthchop_threshold: 0

#####################################################################
#   Z Stepper Settings
#####################################################################

## Z0 Stepper - Front Left
##  Connected to MOTOR_2
[stepper_z]
enable_pin: !PG5
step_pin: PF11
dir_pin: PG3
endstop_pin: PG10

rotation_distance: 40
gear_ratio: 80:16

microsteps: 256

##  Z-position of nozzle (in mm) to z-endstop trigger point relative to print surface (Z0)
##  (+) value = endstop above Z0, (-) value = endstop below
##  Increasing position_endstop brings nozzle closer to the bed
##  After you run Z_ENDSTOP_CALIBRATE, position_endstop will be stored at the very end of your config
#position_endstop: 0.0

position_max: 220
position_min: -2.0

homing_speed: 8.0
second_homing_speed: 3.0
homing_retract_dist: 2.0

[tmc5160 stepper_z]
cs_pin: PC6
spi_bus: spi1
sense_resistor: 0.075

run_current: 1.2
interpolate: false
#stealthchop_threshold: 9999
stealthchop_threshold: 0

##  Z1 Stepper - Rear Left
##  Connected to MOTOR_3
[stepper_z1]
enable_pin: !PA0
step_pin: PG4
dir_pin: !PC1

rotation_distance: 40
gear_ratio: 80:16

microsteps: 256

[tmc5160 stepper_z1]
cs_pin: PC7
spi_bus: spi1
sense_resistor: 0.075

run_current: 1.2
interpolate: false
#stealthchop_threshold: 9999
stealthchop_threshold: 0

##  Z2 Stepper - Rear Right
##  Connected to MOTOR_4
[stepper_z2]
enable_pin: !PG2
step_pin: PF9
dir_pin: PF10

rotation_distance: 40
gear_ratio: 80:16

microsteps: 256

[tmc5160 stepper_z2]
cs_pin: PF2
spi_bus: spi1
sense_resistor: 0.075

run_current: 1.2
interpolate: false
#stealthchop_threshold: 9999
stealthchop_threshold: 0

##  Z3 Stepper - Front Right
##  Connected to MOTOR_5
[stepper_z3]
enable_pin: !PF1
step_pin: PC13
dir_pin: !PF0

rotation_distance: 40
gear_ratio: 80:16

microsteps: 256

[tmc5160 stepper_z3]
cs_pin: PE4
spi_bus: spi1
sense_resistor: 0.075

run_current: 1.2
interpolate: false
#stealthchop_threshold: 9999
stealthchop_threshold: 0

#####################################################################
#   Extruder
#####################################################################

##  Connected to MOTOR_6
##  Heater - HE0
##  Thermistor - T0
[extruder]
enable_pin: !PD4
step_pin: PE2
dir_pin: !PE3

rotation_distance: 35.49256
gear_ratio: 5.18:1

microsteps: 256

full_steps_per_rotation: 200    #200 for 1.8 degree, 400 for 0.9 degree

nozzle_diameter: 0.4
filament_diameter: 1.75

heater_pin: PA2

sensor_type: SliceEngineering 450
sensor_pin: PF4

min_temp: 10
max_temp: 300
max_power: 1.0

min_extrude_temp: 230
max_extrude_cross_section: 5.0

control = pid
pid_kp = 23.676
pid_ki = 1.518
pid_kd = 92.335

# FormFutura TitanX Red, 0.8 mm nozzle, 245C
#pressure_advance: 0.32
#pressure_advance_smooth_time: 0.040

# FormFutura TitanX Red, 0.4 mm nozzle, 245C
#pressure_advance: 0.30
#pressure_advance_smooth_time: 0.030

# ezPC+CF, 0.6 mm nozzle, 275C
#pressure_advance: 0.34
#pressure_advance_smooth_time: 0.030

# Matterhackers Pro ABS Black, 0.4 mm nozzle, 235C
#pressure_advance: 0.32
#pressure_advance_smooth_time: 0.02

# 3DXTECH ASA Black, 0.4 mm nozzle, 245C
pressure_advance: 0.535
pressure_advance_smooth_time: 0.02

[firmware_retraction]
retract_length: 4.0
retract_speed: 50
unretract_extra_length: 0.0
unretract_speed: 50

[tmc5160 extruder]
cs_pin: PE1
spi_bus: spi1
sense_resistor: 0.075

run_current: 1.2
interpolate: true
#stealthchop_threshold: 9999
stealthchop_threshold: 0

#####################################################################
#   Bed Heater
#####################################################################

[heater_bed]
##  SSR Pin - HE1
##  Thermistor - TB
heater_pin: PA3

sensor_type: Generic 3950
sensor_pin: PF3

# 0.4W/cm2 = 0.4 * 25 * 25 = 250W, 100/500 * 250 = 50 -> 0.5
max_power: 0.5

min_temp: 0
max_temp: 120

control = pid
pid_kp = 36.831
pid_ki = 1.860
pid_kd = 182.313

#####################################################################
#   Probe
#####################################################################

[probe]
pin: ^PG12

x_offset: 0
y_offset: 19.75
z_offset: 6.42

speed: 3.0
lift_speed: 20.0

samples: 3
samples_result: median
sample_retract_dist: 3.0
samples_tolerance: 0.015
samples_tolerance_retries: 5

#####################################################################
#   Fan Control
#####################################################################

[fan]
##  Print Cooling Fan - FAN0
pin: PD12
kick_start_time: 0.5
##  Depending on your fan, you may need to increase this value
##  if your fan will not start. Can change cycle_time (increase)
##  if your fan is not able to slow down effectively
off_below: 0.10

[heater_fan hotend_fan]
##  Hotend Fan - FAN1
pin: PE5
max_power: 1.0
kick_start_time: 0.5
heater: extruder
heater_temp: 50.0
##  If you are experiencing back flow, you can reduce fan_speed
#fan_speed: 1.0

#####################################################################
#   LED Control
#####################################################################

# Chamber Lighting - HE2 Connector (Optional)
[output_pin caselight]
pin: PB10
pwm: true
shutdown_value: 0
value: 1
cycle_time: 0.01

#####################################################################
#   Homing and Gantry Adjustment Routines
#####################################################################

[idle_timeout]
timeout: 1800

# Disabled by Klicky mod
#[safe_z_home]
#home_xy_position: 176, 256
#speed: 100
#z_hop: 10

[quad_gantry_level]
##  Use QUAD_GANTRY_LEVEL to level a gantry.
##  Min & Max gantry corners - measure from nozzle at MIN (0,0) and 
##  MAX (250, 250), (300,300), or (350,350) depending on your printer size
##  to respective belt positions

gantry_corners:
   -60,-10
   310, 320
points:
   50,25
   50,175
   200,175
   200,25
    
speed: 300
horizontal_move_z: 13
retries: 5
retry_tolerance: 0.0075
max_adjust: 4
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

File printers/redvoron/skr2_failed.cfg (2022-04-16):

[include mainsail.cfg]

# This file contains common pin mappings for the BigTreeTech SKR 2.
# To use this config, the firmware should be compiled for the
# STM32F407 with a "32KiB bootloader".

# In newer versions of this board shipped in late 2021 the STM32F429
# is used, if this is the case compile for this with a "32KiB bootloader"
# You will need to check the chip on your board to identify which you have.
#
# The "make flash" command does not work on the SKR 2. Instead,
# after running "make", copy the generated "out/klipper.bin" file to a
# file named "firmware.bin" on an SD card and then restart the SKR 2
# with that SD card.

# See docs/Config_Reference.md for a description of parameters.

# Note: The initial revision of this board has a flaw that can cause
# damage to itself and other boards. Be sure to verify the board is
# not impacted by this flaw before using it.


################################################################################

[mcu]
serial: /dev/serial/by-id/usb-Klipper_stm32f407xx_200020001647393530343239-if00

[mcu z]
serial: /dev/serial/by-id/usb-Klipper_stm32f407xx_240036000147393438343535-if00

[printer]
kinematics: corexy
max_velocity: 300  
max_accel: 3000    			#Max 4000
max_z_velocity: 15 			#Max 15 for 12V TMC Drivers, can increase for 24V
max_z_accel: 350
square_corner_velocity: 5.0


################################################################################

[stepper_x]
# B motor
enable_pin: !PE3
step_pin: PE2
dir_pin: PE1

microsteps: 32
rotation_distance: 40
full_steps_per_rotation: 200 # 1.8 degree stepper

homing_speed: 25 # max 100
homing_retract_dist: 5
homing_positive_dir: true

# FIXME
endstop_pin: PC1

position_min: 0
position_endstop: 250
position_max: 250

[tmc2209 stepper_x]
uart_pin: PE0
interpolate: False
run_current: 0.8
sense_resistor: 0.110
stealthchop_threshold: 0


################################################################################

[stepper_y]
enable_pin: !PD6
step_pin: PD5
dir_pin: !PD4

microsteps: 32
rotation_distance: 40
full_steps_per_rotation: 200 # 1.8 degree stepper

homing_speed: 25 # max 100
homing_retract_dist: 5
homing_positive_dir: true

# FIXME
endstop_pin: PC3

position_min: 0
position_endstop: 250
position_max: 250

[tmc2209 stepper_y]
uart_pin: PD3
interpolate: False
run_current: 0.8
sense_resistor: 0.110
stealthchop_threshold: 0


################################################################################

[stepper_z]
# Front Left motor in z:XM
enable_pin: !z:PE3
step_pin: z:PE2
dir_pin: z:PE1

gear_ratio: 80:16
microsteps: 32
rotation_distance: 40

endstop_pin: z:PC0

##  Z-position of nozzle (in mm) to z-endstop trigger point relative to print surface (Z0)
##  (+) value = endstop above Z0, (-) value = endstop below
##	Increasing position_endstop brings nozzle closer to the bed
##  After you run Z_ENDSTOP_CALIBRATE, position_endstop will be stored at the very end of your config
position_endstop: -0.5

position_min: -5
position_max: 230

homing_speed: 8
second_homing_speed: 3
homing_retract_dist: 3

[tmc2209 stepper_z]
uart_pin: z:PE0
interpolate: False
run_current: 0.800
sense_resistor: 0.110
stealthchop_threshold: 0

[stepper_z1]
# Back Left motor in z:YM
enable_pin: !z:PD6
step_pin: z:PD5
dir_pin: z:PD4

gear_ratio: 80:16
microsteps: 32
rotation_distance: 40

[tmc2209 stepper_z1]
uart_pin: z:PD3
interpolate: False
run_current: 0.8
sense_resistor: 0.110
stealthchop_threshold: 0

[stepper_z2]
# Back Right motor in z:ZM
enable_pin: !z:PD1
step_pin: z:PA15
dir_pin: !z:PA8

gear_ratio: 80:16
microsteps: 32
rotation_distance: 40

[tmc2209 stepper_z2]
uart_pin: z:PD0
interpolate: False
run_current: 0.8
sense_resistor: 0.110
stealthchop_threshold: 0

[stepper_z3]
# Front Right motor in z:E0
enable_pin: !z:PC7
step_pin: z:PD15
dir_pin: z:PD14

gear_ratio: 80:16
microsteps: 32
rotation_distance: 40

[tmc2209 stepper_z3]
uart_pin: z:PC6
interpolate: False
run_current: 0.8
sense_resistor: 0.110
stealthchop_threshold: 0


################################################################################

[extruder]
enable_pin: !PC7
step_pin: PD15
dir_pin: PD14
microsteps: 16
rotation_distance: 35.49256
gear_ratio: 5.18:1
nozzle_diameter: 0.400
filament_diameter: 1.750
heater_pin: PB3
sensor_type: SliceEngineering 450
sensor_pin: PA2
control: pid
pid_kp: 26.213
pid_ki: 1.304
pid_kd: 131.721
min_temp: 0
max_temp: 300

[tmc2209 extruder]
uart_pin: PC6
interpolate: false
run_current: 1.2
sense_resistor: 0.110
stealthchop_threshold: 0


################################################################################

[heater_bed]
heater_pin: PB7
sensor_type: Generic 3950
sensor_pin: PA1
min_temp: 0
max_temp: 110
control: pid
pid_kp: 58.437
pid_ki: 2.347
pid_kd: 363.769


################################################################################

[heater_fan hotend_fan]
pin: PB5
max_power: 1.0
kick_start_time: 0.5
heater: extruder
heater_temp: 20.0

[fan]
pin: PB6
off_below: 0.10


################################################################################

[probe]
pin: ^PE4
x_offset: 0
y_offset: 25.0
z_offset: 0
speed: 10.0

samples: 3
samples_result: median
sample_retract_dist: 3.0
samples_tolerance: 0.006
samples_tolerance_retries: 3


################################################################################

# Due to BTT implementing a Marlin-specific safety feature,
# "anti-reversal stepper protection", this pin needs pulling
# high to pass power to stepper drivers and most FETs

[output_pin motor_power]
pin: PC13
value: 1


################################################################################

[display]
lcd_type: uc1701
cs_pin: z:PB1
a0_pin: z:PE9
rst_pin: z:PE10
contrast: 63
encoder_pins: ^z:PB2, ^z:PE7
click_pin: ^!z:PB0
## Some micro-controller boards may require an spi bus to be specified:
#spi_bus: spi
# Alternatively, some micro-controller boards may work with software spi:
spi_software_miso_pin: z:PA6
spi_software_mosi_pin: z:PA7
spi_software_sclk_pin: z:PA5

[output_pin beeper]
pin: z:PC5

[neopixel btt_mini12864]
pin: z:PE11
chain_count: 3
color_order: RGB
initial_RED: 0.5
initial_GREEN: 0.5
initial_BLUE: 0.5

#	Set RGB values on boot up for each Neopixel. 
# Index 1 = Left Dial
# Index 2 = Right Dial
# Index 3 = Screen
[delayed_gcode setdisplayneopixel]
initial_duration: 1
gcode:
        SET_LED LED=btt_mini12864 RED=1 GREEN=0 BLUE=0 INDEX=1 TRANSMIT=0
        SET_LED LED=btt_mini12864 RED=1 GREEN=0 BLUE=0 INDEX=2 TRANSMIT=0
        SET_LED LED=btt_mini12864 RED=1 GREEN=1 BLUE=1 INDEX=3 


################################################################################

[filament_switch_sensor RunoutSensor]
pause_on_runout: False
runout_gcode: PAUSE
insert_gcode: RESUME
switch_pin: !PC2


################################################################################

[output_pin caselight]
pin: PD7
pwm: true
shutdown_value: 0
value: 0
cycle_time: 0.01

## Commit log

2022-05-08 Finish PiCam mount
    [2020Mount.stl, CaseTop.stl, PCBHolder.stl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]
2022-05-16 Add MEAN WELL PSU stack mod
    [MeanwellStackLeft.stl, MeanwellStackRight.stl]
2022-05-18 pins mod
    [MGN12_xy_joint_left_lower_pinned_24r2_cfx.stl, MGN12_xy_joint_left_upper_pinned_24r2_cfx.stl, MGN12_xy_joint_right_lower_pinned_24r2_cfx.stl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]
